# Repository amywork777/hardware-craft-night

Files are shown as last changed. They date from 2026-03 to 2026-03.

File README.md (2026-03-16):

# Custom LED PCBs for Hardware Craft Night

**Date:** March 13, 2026
**Category:** Hardware Projects

## Event Details
- **When:** April 9, 6:30pm
- **Where:** Vizcom
- **Co-hosting with:** Shivani Patel (Telemetron)
- **Logos on back:** Vizcom + Telemetron

## Shapes
- Heart
- Star
- Flower

## Design Requirements
- Simple circuit: CR2032 → switch → resistor → LEDs → GND (no microcontroller)
- Through-hole components only (beginners will solder)
- Hole at top for keychain/jewelry attachment
- Size: ~30-40mm

---

## Design Tools

### tscircuit (recommended by Seve @seveibar)
- React/TypeScript PCB design tool
- Write code → generates schematic, PCB, 3D preview, fabrication files
- Built-in autorouting
- Exports directly to JLCPCB
- https://tscircuit.com
- Docs: https://docs.tscircuit.com

### EasyEDA (traditional)
- Draw shape in Inkscape, import SVG
- Manual component placement and routing
- Export gerbers for JLCPCB

---

## Open Source References

### Heart
- PCBWay Heart Necklace by Arnov Sharma (best looking, but SMD + MCU): https://www.pcbway.com/project/shareproject/PCB_Heart_Necklace_3c1cbe5a.html
- CAROBOT Glowing Heart (KiCad, more beginner-friendly): https://github.com/carobot/CAROBOT-Glowing-Heart-LED-Kit

### Star
- led-star-pcb by HeyJoFlyer (MIT license, simple): https://github.com/HeyJoFlyer/led-star-pcb

### Flower
- No good open source exists - design from scratch

---

## Workshop Supplies (~$220 for 25 people)

### Soldering
- 8-10 soldering stations (1 per 3 people)
- Solder 63/37 rosin core 0.6mm (2 spools)
- Brass tip cleaners (8-10)
- Helping hands (8-10)

### Electronics (30 kits = 25 + spares)
- 35 custom PCBs from JLCPCB (~$2-5 each, order in 5 colors)
- 60 CR2032 batteries
- 35 CR2032 coin cell holders (through-hole)
- 300 5mm LEDs assorted colors
- 200 68Ω resistors (1/4W through-hole)
- 35 slide switches

### Jewelry Findings
- 50 split key rings (25mm)
- 30 ball chain necklaces (18-24")
- 200 jump rings (6mm, gold + silver mix)
- 30 pairs earring hooks
- 50 lobster claw clasps

### Craft/Decoration
- 30 small sorting trays
- Printed instruction cards (laminated)
- 30 zip bags
- Nail polish for decorating edges
- Stickers/washi tape

### Safety
- 25 safety glasses (required)
- 2-3 fume extractors or box fan

---

## Claude Prompt for Designing

```
i need to design 3 simple LED PCBs for a beginner craft workshop using tscircuit (or EasyEDA/JLCPCB):

1. heart shaped
2. star shaped  
3. flower shaped

requirements:
- simple circuit: coin cell battery (CR2032), 2-4 LEDs, resistors
- through-hole components only (beginners will solder)
- hole at top for keychain/jewelry attachment
- back silkscreen should have space for two company logos
- size: roughly 30-40mm
- should light up when battery inserted

please walk me through:
1. the schematic design (component values)
2. creating custom board shapes
3. component placement
4. routing traces
5. adding silkscreen logos
6. generating fabrication files for JLCPCB
```

---

## Timeline
- Order PCBs 3-4 weeks before April 9 (by ~March 12-16)
- JLCPCB turnaround: ~1 week production + shipping

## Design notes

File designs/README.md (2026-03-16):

# Hardware Craft Night - LED PCB Designs

Three shaped LED PCBs designed with [tscircuit](https://tscircuit.com) for a beginner workshop.

**Event:** April 9, 2026 at 6:30pm at Vizcom  
**Co-hosts:** Vizcom + Telemetron (Shivani Patel)

## Assembly Strategy

### Pre-assembled by JLCPCB (SMD):
- **R1:** 68Ω resistor (0603 SMD)
- **SW1:** Slide switch (SMD)
- **BAT1:** CR2032 battery holder (SMD or THT, whatever JLCPCB stocks)

### Through-hole pads only (workshop assembly):
- **LED footprints:** 5mm through-hole LED size (2.54mm pin spacing, 1.0mm holes)
- Just holes/pads on the PCB - no components pre-installed

### At the workshop, people will:
1. Pick their LED colors from a selection
2. Push LED legs through the holes
3. Bend legs flat on the back to make contact (no soldering needed!)
4. Pop in a CR2032 battery

## Designs

### 1. ❤️ Heart (heart.tsx)
- **Shape:** Parametric heart curve, ~32mm × 29mm
- **LEDs:** 3× through-hole pads arranged in heart pattern
- **Color:** Red PCB recommended

### 2. ⭐ Star (star.tsx)
- **Shape:** 5-pointed star, ~32mm × 31mm
- **LEDs:** 5× through-hole pads (one at each tip!)
- **Color:** Blue or black PCB recommended

### 3. 🌸 Flower (flower.tsx)
- **Shape:** 6-petal flower, ~32mm × 28mm
- **LEDs:** 4× through-hole pads in alternating petals
- **Color:** Green or purple PCB recommended

## Circuit (same for all 3)

```
CR2032 (3V) → Slide Switch → 68Ω Resistor → LED pads (parallel) → GND
```

All LED pads are wired in parallel. Each gets ~15mA through the shared 68Ω resistor.

**Note:** The star board draws the most current (5 LEDs × 15mA = 75mA). Consider using 100Ω resistors for the star to extend CR2032 battery life.

## Component Values

| Component | Value | Package | Assembly | Qty/Board |
|---|---|---|---|---|
| Battery holder | CR2032 | SMD coin cell | JLCPCB | 1 |
| Slide switch | SPST | SMD | JLCPCB | 1 |
| Resistor | 68Ω | 0603 SMD | JLCPCB | 1 |
| LED pads | 5mm THT | 2.54mm pitch holes | Workshop | 3-5 |
| Mounting hole | 2.5mm | — | — | 1 |

## Bill of Materials (25 people, ~35 PCBs total)

### JLCPCB Order (PCBs + SMT Assembly)
| Item | Qty | Notes |
|---|-----|---|
| Heart PCBs (assembled) | 12 | With R1, SW1, BAT1 pre-soldered |
| Star PCBs (assembled) | 12 | With R1, SW1, BAT1 pre-soldered |
| Flower PCBs (assembled) | 12 | With R1, SW1, BAT1 pre-soldered |

### Workshop Supplies
| Item | Qty | Notes |
|---|-----|---|
| CR2032 batteries | 60 | Spares (people pop these in) |
| 5mm Red LEDs | 40 | Assorted for picking |
| 5mm Yellow LEDs | 40 | |
| 5mm Green LEDs | 40 | |
| 5mm Blue LEDs | 40 | |
| 5mm White LEDs | 20 | |
| Jump rings (8mm) | 40 | For keychain attachment |
| Key rings | 15 | |
| Ball chain necklaces (24") | 15 | |
| Earring hooks | 10 pairs | |
| Safety glasses | 25 | For LED leg bending |

## How to Use

### Preview locally
```bash
npm install
npx tsci dev heart.tsx
```

### Export for manufacturing
```bash
npx tsci export heart.tsx -f gerber
npx tsci export star.tsx -f gerber
npx tsci export flower.tsx -f gerber
```

Upload the gerber ZIP files to [JLCPCB](https://jlcpcb.com).

### Recommended JLCPCB settings
- Quantity: 10-15 per design
- Layers: 2
- Thickness: 1.6mm
- Solder mask color: match the design theme
- Silkscreen: white
- Surface finish: HASL (lead-free)
- **SMT Assembly: Yes** (select Economic PCBA)
- Upload BOM + pick and place files for R1, SW1, BAT1

## PCB Order Timeline
**Order by March 16** for delivery before April 9.
- JLCPCB standard shipping + assembly: ~2-3 weeks

## Estimated Total Cost: ~$180

| Category | Est. Cost |
|---|---|
| PCBs + SMT assembly (3 designs × 12) | $80 |
| LEDs (bulk 5mm assorted) | $15 |
| CR2032 batteries (60) | $15 |
| Jewelry hardware | $20 |
| Safety glasses + misc | $50 |
| **Total** | **~$180** |

**Note:** No soldering stations needed! People just push LEDs through holes and bend legs. Much simpler workshop setup than before.

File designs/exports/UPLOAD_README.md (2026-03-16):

# JLCPCB Upload Instructions

## Files to Upload (for each board)

### HEART
- Gerbers: `heart-gerbers.zip`
- BOM: `heart_bom.csv`
- CPL: `heart_cpl.csv`

### FLOWER
- Gerbers: `flower-gerbers.zip`
- BOM: `flower_bom.csv`
- CPL: `flower_cpl.csv`

## JLCPCB Assembly Flow

1. Go to jlcpcb.com → Order Now
2. Upload gerbers ZIP for each board
3. Set: Qty 35, 2-layer, HASL lead-free, pick solder mask color
4. Toggle "PCB Assembly" ON → Economic PCBA
5. Upload BOM file when prompted
6. Upload CPL file when prompted
7. Match components (should auto-match with LCSC numbers)
8. Add to cart

## Components (same for all boards)

| Designator | Value | Footprint | LCSC Part # |
|---|---|---|---|
| R1 | 68Ω | 0603 | C22966 |
| SW1 | Slide Switch SPDT | SW_MK-12C02 | C128955 |
| BAT1 | CR2032 Holder | BAT_CR2032_SMD | C70377 |

LEDs are left empty — through-hole pads assembled at workshop.

## Recommended Settings per Board

| Board | Qty | Solder Mask Color |
|---|-----|---|
| Heart | 35 | Red |
| Flower | 35 | Green or Purple |

## Important Notes

- Gerbers need to be re-exported after design updates (LED additions)
- The BOM/CPL files use JLCPCB standard format
- Both boards use identical SMD components

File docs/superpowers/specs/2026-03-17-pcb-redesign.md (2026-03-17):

# PCB Redesign Spec — Hardware Craft Night

## Context

Feedback from EE friends identified mechanical interference (battery covering switch), unreliable LED connection (loose through-holes), sharp heart tip, and unnecessary vias. Also splitting into Vizcom and Telemetron branded variants.

## Changes

### 1. File Structure

Split each shape into two brand variants. Extract shared components.

| File | Description |
|---|---|
| `components.tsx` | Shared SmtBattery, SmtSwitch, LedSocket footprints |
| `heart-vizcom.tsx` | Heart PCB with Vizcom logo on back |
| `heart-telemetron.tsx` | Heart PCB with Telemetron logo + text on back |
| `flower-vizcom.tsx` | Flower PCB with Vizcom logo on back |
| `flower-telemetron.tsx` | Flower PCB with Telemetron logo + text on back |
| `logos.tsx` | Logo silkscreen paths (unchanged) |

Old `heart.tsx` and `flower.tsx` are removed.

### 2. Component Layout — Heart

Spread components to avoid battery overlap. CR2032 is 20mm diameter.

| Component | Position | Rationale |
|---|---|---|
| BAT1 (CR2032 holder) | (0, 5) | Center of heart, biggest component |
| SW1 (slide switch) | (-10, -8) | Left lobe, accessible, not under battery |
| R1 (68Ω 0603) | (-7, -5) | Near switch, along trace path |
| LED1 (2-pin socket) | (0, -5) | Center-top, visible, clear of battery |
| Keychain hole | (0, -16) | In bail tab between lobes |

### 3. Component Layout — Flower

| Component | Position | Rationale |
|---|---|---|
| BAT1 (CR2032 holder) | (0, 3) | Center |
| SW1 (slide switch) | (-5, -3) | Offset left, clear of battery |
| R1 (68Ω 0603) | (-3, -5) | Near switch |
| LED1 (2-pin socket) | (0, -6) | Center stamen |
| Keychain hole | (10, 17) | Lower-right petal |

### 4. LED Socket

Replace `ThruHoleLed` plated holes (1.0mm holes, 2.54mm pitch) with a **2-pin 2.54mm female pin header** pre-soldered by JLCPCB.

- LCSC part: C49661 (1x2P 2.54mm female header) or equivalent
- JLCPCB solders it during assembly
- Attendees push 5mm LED legs straight into the socket — no tools, no soldering
- LED legs are exactly 2.54mm pitch, so they click right in

Update BOM files to include the header. Update the footprint to use standard 2.54mm pitch through-hole pads with appropriate hole size for the header pins (~1.0mm).

### 5. Round Heart Tip

Replace the sharp point at (0, 23.91) with a rounded end (~2mm radius). Modify the outline points near the tip to curve smoothly instead of converging to a needle point.

Before: `(0.20, 22.96), (0.03, 23.67), (0.00, 23.91), (-0.03, 23.67), (-0.20, 22.96)`

After: Replace with points that form a ~2mm radius semicircle at the bottom.

### 6. Back Silkscreen Logos

Each board variant gets ONE logo on the back:

- `*-vizcom.tsx`: VizcomLogo centered on back
- `*-telemetron.tsx`: TelemetronIcon + TelemetronText centered on back

Logo positions adjusted per shape to be centered and visible.

### 7. BOM/CPL Updates

Add LED socket header to BOM for all 4 variants:

```
Comment,Designator,Footprint,LCSC Part #
68R,R1,0603,C22966
Slide Switch,SW1,SW_MK-12C02,C128955
CR2032 Holder,BAT1,BAT_CR2032_SMD,C70377
1x2P Female Header 2.54mm,J1,HDR_1x2_2.54mm,C49661
```

CPL files updated with new component positions per variant.

### 8. Circuit

Unchanged: `CR2032 → SW1 → R1 (68Ω) → LED socket → GND`

All LEDs in parallel if multiple (currently 1 per board).

### 9. What We're NOT Changing

- Board outlines (except rounding heart tip)
- Circuit schematic
- Board dimensions
- Keychain hole positions
- Manufacturing process (JLCPCB PCBA)

## Acceptance Criteria

- All components inside board outlines with no physical overlap
- Battery does not cover switch or LED socket
- Switch accessible with battery installed
- LED socket uses 2-pin female header (JLCPCB pre-soldered)
- Heart tip rounded, not sharp
- 4 board variants exported with gerbers + BOM/CPL
- Each variant has correct single-brand logo on back

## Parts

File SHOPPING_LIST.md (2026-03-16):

# Hardware Craft Night - Shopping List

**Event:** April 9, 2026 at 6:30pm at Vizcom  
**Attendees:** ~25 people  
**Co-hosts:** Vizcom + Telemetron

---

## PCBs from JLCPCB (order by March 16)

| Item | Qty | Est. Cost | Notes |
|---|-----|---|---|
| Heart PCBs (SMT assembled) | 12 | ~$25 | Red solder mask recommended |
| Star PCBs (SMT assembled) | 12 | ~$25 | Blue or black solder mask |
| Flower PCBs (SMT assembled) | 12 | ~$30 | Green or purple solder mask |

**Pre-assembled on each PCB:**
- 68Ω resistor (0603 SMD)
- Slide switch (SMD)
- CR2032 battery holder

**Total PCB cost:** ~$80 (includes assembly + shipping)

---

## Electronics (Amazon/DigiKey/AliExpress)

| Item | Qty | Est. Cost | Link Notes |
|---|-----|---|---|
| CR2032 batteries | 60 | $12 | Bulk pack, 2+ per person |
| 5mm LEDs - Red | 50 | $3 | |
| 5mm LEDs - Yellow | 50 | $3 | |
| 5mm LEDs - Green | 50 | $3 | |
| 5mm LEDs - Blue | 50 | $3 | |
| 5mm LEDs - White | 30 | $2 | |
| 5mm LEDs - Pink | 30 | $3 | |

**Total electronics:** ~$29

---

## Jewelry Findings (Amazon/Michaels)

| Item | Qty | Est. Cost | Notes |
|---|-----|---|---|
| Jump rings 6-8mm (gold + silver mix) | 100 | $5 | For attaching to chains |
| Split key rings 25mm | 30 | $4 | Keychain option |
| Ball chain necklaces 24" | 25 | $8 | Necklace option |
| Lobster clasps | 30 | $4 | |
| Earring hooks | 20 pairs | $5 | Earring option |
| Thin cord/ribbon assorted | 3 spools | $6 | DIY necklace alternative |

**Total jewelry findings:** ~$32

---

## Craft Supplies (Michaels/Amazon)

| Item | Qty | Est. Cost | Notes |
|---|-----|---|---|
| Small sorting trays | 10 | $8 | For LED color stations |
| Needle-nose pliers | 8 | $16 | For bending LED legs |
| Wire cutters/flush snips | 4 | $10 | For trimming LED legs |
| Small zip bags | 30 | $4 | Take-home bags |
| Washi tape assorted | 1 pack | $6 | Board decoration |
| Nail polish assorted | 6 | $12 | Edge decoration |
| Stickers/gems | 1 pack | $5 | Decoration |

**Total craft supplies:** ~$61

---

## Safety

| Item | Qty | Est. Cost | Notes |
|---|-----|---|---|
| Safety glasses | 25 | $20 | For trimming/bending LED legs |

**Total safety:** ~$20

---

## Optional Nice-to-Haves

| Item | Qty | Est. Cost | Notes |
|---|-----|---|---|
| Printed instruction cards (laminated) | 30 | $15 | Step-by-step visual guide |
| Tablecloths | 3 | $10 | Protect tables |
| LED color label signs | 6 | $0 | Print yourself |
| Extra batteries | 20 | $5 | Replacements |

**Total optional:** ~$30

---

## Grand Total

| Category | Cost |
|---|---|
| PCBs + assembly | $80 |
| Electronics | $29 |
| Jewelry findings | $32 |
| Craft supplies | $61 |
| Safety | $20 |
| **Subtotal** | **$222** |
| Optional extras | $30 |
| **Grand Total** | **~$250** |

---

## Workshop Flow (no soldering!)

1. **Pick a PCB** - heart, star, or flower
2. **Pick LED colors** - grab from color-sorted trays
3. **Insert LEDs** - push legs through holes (+ marking = long leg)
4. **Bend legs** - use pliers to bend flat on back
5. **Trim legs** - snip excess with wire cutters
6. **Insert battery** - CR2032, flat side up
7. **Test!** - flip switch, LEDs light up
8. **Decorate** - nail polish, stickers, washi tape
9. **Add hardware** - jump ring through hole, attach to keychain/necklace

**Time per person:** ~10-15 minutes

---

## Order Timeline

| Date | Action |
|---|---|
| March 16 | Order PCBs from JLCPCB |
| March 20 | Order electronics + supplies from Amazon |
| April 1 | PCBs arrive (allow buffer) |
| April 7 | Verify all supplies, prep stations |
| April 9 | 🎉 Hardware Craft Night! |

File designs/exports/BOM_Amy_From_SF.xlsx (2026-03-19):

ID | Name | Designator | Footprint | Quantity | Manufacturer Part | Manufacturer | Supplier | Supplier Part
1 | MY-2032-12 | BT2 | BAT-SMD_MY-2032-12 | 1 | MY-2032-12 | MYOUNG(美阳) | LCSC | C964833
2 | TJ-L5FYTGCRTFCSFLC2R-A5 | LED1,LED2,LED3 | LED-TH_BD5.8-P2.54-FD | 3 | TJ-L5FYTGCRTFCSFLC2R-A5 | TOGIALED(统佳)
3 | 68Ω | R1,R2,R3 | R0805 | 3 | 0805W8F680JT5E | UNI-ROYAL(厚声) | LCSC | C17802
4 | HX MST22D18G2 | U1 | SW-SMD_MST22D18G2 | 1 | HX MST22D18G2 | hanxia(韩下) | LCSC | C5149822

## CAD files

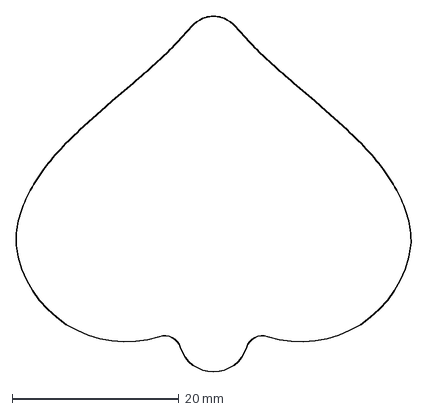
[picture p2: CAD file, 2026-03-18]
designs/exports/heart-sketch-2mm.dxf
47.3 x 42.6 mm

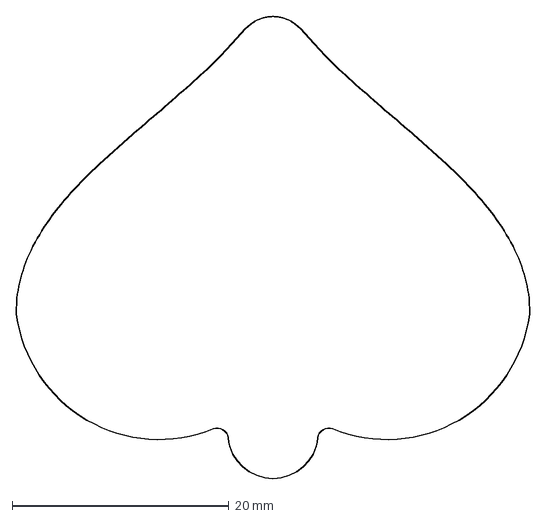
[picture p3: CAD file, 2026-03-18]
designs/exports/heart-sketch-1mm.dxf
47.3 x 42.6 mm

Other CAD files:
designs/exports/heart-outline-2mm-fillet-smooth.dxf
designs/exports/heart-outline-no-bail.dxf
designs/exports/heart-outline-1mm-fillet.dxf
designs/exports/heart-outline-2mm-fillet.dxf
designs/exports/heart-outline.dxf

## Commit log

2026-03-16 Initial commit: heart & flower LED PCB designs for Hardware Craft Night
    Beginner soldering workshop at Vizcom, April 9 2026, co-hosted with Telemetron.
    - Heart PCB: 3 LEDs, bail tab for keychain, red solder mask
    - Flower PCB: 2 LED stamens in center, purple solder mask
    - Clean Vizcom + Telemetron logos on back silkscreen
    - BOM/CPL files ready for JLCPCB PCBA
    - Gerbers exported and ready to upload
    [flower.kicad_pcb, flower.kicad_sch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]
2026-03-16 Simplify to 1 LED per board
2026-03-16 Move flower hole to upper petal, add Telemetron text label
2026-03-16 Center flower hole in upper-right petal
2026-03-16 Flip Vizcom logo orientation, move flower hole to lower-right petal
2026-03-16 Mirror logos for bottom layer, move flower hole to petal edge
2026-03-16 Move flower hole slightly right to (11, 17)
2026-03-16 Nudge flower hole to (10, 17)
2026-03-16 Add real gerber zips for JLCPCB ordering
2026-03-16 Add real gerber zips
2026-03-16 Add BOM/CPL files
    [heart_bom.csv]
2026-03-17 Add PCB redesign spec
2026-03-17 Redesign PCBs: spread layout, LED socket, rounded heart tip, 4 brand variants
    - Extract shared components to components.tsx (SmtBattery, SmtSwitch, LedSocket)
    - Replace ThruHoleLed with 2-pin female header socket (J1, LCSC C49661)
    JLCPCB pre-solders the socket, attendees just push LED in
    - Spread components to avoid battery covering switch
    Switch moved to left lobe (heart) / offset left (flower)
    - Round heart tip from needle point to ~2mm radius
    - Split into 4 brand variants:
    heart-vizcom, heart-telemetron, flower-vizcom, flower-telemetron
    - Update BOM with J1 header, update CPL positions
    - Old heart.tsx and flower.tsx kept for reference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
    [flower_bom.csv, heart_bom.csv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]
2026-03-17 Spread components: LED top-center, switch in right lobe, fix flower layout
    Heart: LED at (0,-10), switch at (12,-8), R1 at (6,-8), battery at (0,5)
    Flower: LED at (0,-6), switch at (5,-4), R1 at (3,-6), battery at (0,4)
    [flower_cpl.csv, heart_cpl.csv]
2026-03-17 Rounder heart tip (~5mm radius), more heart-shaped
2026-03-17 Heart tip: split the difference — pointed but rounded ~3mm end
2026-03-17 Heart tip: in between — V-shape but wider 4mm rounded end
2026-03-17 Move logos to front silkscreen in left lobe
2026-03-17 Fix front logo mirroring — negate X so it reads correctly in render
2026-03-17 Fix front logo reading direction, shift back logo below battery
2026-03-17 Shrink back logo to ~22mm, move front logo inside heart bounds
2026-03-18 Fix footprints, clearance, bail width, and polarity indicator
    - Battery footprint: match LCSC C70377, add mechanical anchor pads
    - Switch footprint: match LCSC C128955, correct 1.0mm pitch
    - Move switch to (15,-8) and R1 to (10,-8) for battery clearance
    - Widen bail tab from 6mm to 8mm for keychain strength
    - Add cathode flat-edge indicator on LED socket
    [heart_cpl.csv]
2026-03-18 Fix front logo orientation — reads correctly on front, mirrored on back
2026-03-18 Export KiCad PCB files for manual routing
    tscircuit autorouter produces poor results for this simple circuit.
    KiCad files allow manual single-layer routing and proper footprints.
    [heart-telemetron.kicad_pcb, heart-vizcom.kicad_pcb]
2026-03-18 Add fillets at bail-lobe junctions, export DXF outline for KiCad
    - Added ~1.5mm radius fillets where bail tab meets heart lobes
    (CNC routers can't cut internal sharp corners)
    - Exported heart-outline.dxf for import into KiCad
    - Re-exported KiCad PCB files with filleted outline
    [heart-outline.dxf, heart-telemetron.kicad_pcb, heart-vizcom.kicad_pcb]
2026-03-18 Proper fillets at bail-lobe junctions — smooth S-curve, ~2mm min radius
2026-03-18 Simple fillet at bail-lobe junction — smooth radius, no S-curve
2026-03-18 1mm fillet radius at bail-lobe junctions
2026-03-18 2mm fillet radius at bail-lobe junctions
2026-03-18 Fix fillet direction — curves outward to fill concave corner
2026-03-18 2mm fillet at both bail-lobe corners, keep heart shape intact
2026-03-18 Add DXF outlines: 1mm and 2mm fillet versions
    [heart-outline-1mm-fillet.dxf, heart-outline-2mm-fillet.dxf]
2026-03-18 Smooth DXF outlines with 300+ points from parametric heart curve
    - heart-outline-2mm-fillet-smooth.dxf: full heart with bail tab, smooth curves
    - heart-outline-no-bail.dxf: just the heart shape, no bail
    [heart-outline-2mm-fillet-smooth.dxf, heart-outline-no-bail.dxf]
2026-03-18 Smooth DXF: same outline with Catmull-Rom spline interpolation (496 points)
    [heart-outline-2mm-fillet-smooth.dxf]
2026-03-18 Replace heart outline with CAD-designed shape (2mm fillets, smooth curves)
    Heart outline from Amy's CAD software with proper arcs and 2mm fillets
    at bail-lobe junctions. 310 smooth points, 47.3mm x 42.6mm.
    [heart-sketch-1mm.dxf, heart-sketch-2mm.dxf]
2026-03-18 Move keychain hole to (0, -19) closer to bail edge
2026-03-18 Nudge keychain hole to (0, -18) — split the difference
2026-03-18 Re-export all 4 variants: SVGs, gerbers, KiCad files
    All designs current with CAD heart outline, updated components, and logos.
    [heart-telemetron.kicad_pcb, heart-vizcom.kicad_pcb]
2026-03-19 Add engineer's EasyEDA gerbers, BOM, and project file
    Gerber_PCB1_2026-03-19.zip - production-ready gerbers from CircuitoFrito
    BOM_Amy_From_SF.xlsx - bill of materials
    ProPrj_Amy_From_SF.epro - EasyEDA project file
    [BOM_Amy_From_SF.xlsx]
2026-03-19 Add pick-and-place CSV from EasyEDA
    [PickAndPlace_PCB1_2026-03-19.csv]
2026-03-19 Add Telemetron heart gerbers from EasyEDA
